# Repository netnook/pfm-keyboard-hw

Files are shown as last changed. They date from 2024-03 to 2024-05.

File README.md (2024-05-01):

# PFM keyboard

This repo contains the hardware design for the PFM (Perfect For Me) keyboard.
This is a 38 key split keyboard which - as hinted by the name - is designed specifically for me, 
my hands, my typing habits and so on. 

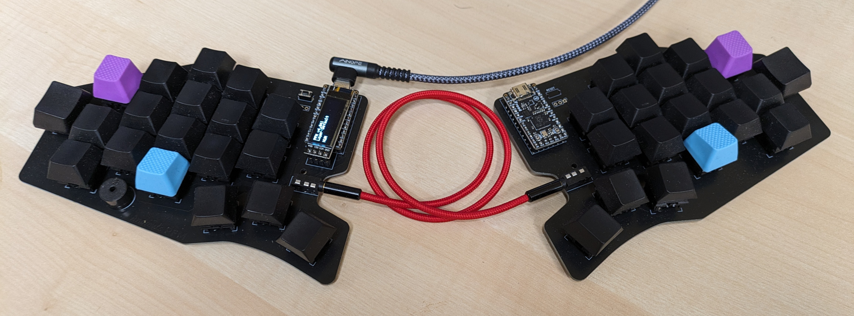
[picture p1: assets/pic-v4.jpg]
My keyboard


**Outline**

Shape Outline

In particular: 
- it has a relatively strong stagger
- the inner most index finger colum has only two keys
- the top most keys of the pinky column are actually used with the ring fingers (those keys are 
spaced a little further up)
- the outer most columns have only one key for the pinky to find.  

Together this reduces overstretching leading to better comfort and reduces the need for hand movement and my tendency to loose my home position when I do so.
Despite the name, it is still not perfect.

*Note: I actually don't use the fourth (lowest) key in the middle finger column - my middle finger does not seem to be able to memorize 2 different downward 
travel distances - and it will likely be removed in a future version.*

The keyboard is based on the [frood microcontroller](https://42keebs.eu/shop/parts/controllers/frood-rp2040-pro-micro-controller/) which allows the use of 38 keys without any diodes.

The board uses MX keys both with hot-swap sockets or directly soldered.

QMK based firmware for this board is available in the [pfm-keyboard-fw](https://github.com/netnook/pfm-keyboard-fw) repo.

## Schematic

Schematic

[Schematic as PDF](/assets/schematic.pdf)

## Parts

- 2x [frood microcontroller](https://42keebs.eu/shop/parts/controllers/frood-rp2040-pro-micro-controller/)
- sockets for MCU (optional)
- OLED display (link ?)
- sockets for display (this also allows bridging the distance required to allow the display to lay above the mcu - long pins could be used instead)
- 38x MX switches and keycaps of choice 
- 38x MX sockets - (optional - PCB can be used with or without sockets)
- 1 or 2 reset switches such as [this](https://42keebs.eu/shop/parts/components/reset-switch/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) - (optional - right hand side only needs programming once and the tiny reset switch on the mcu does the job, for the left hand side which is re-programmed with every layout change the switch is convenient to have)
- piezo buzzer (source ?)
- 2x TRRS socket such as [this](https://42keebs.eu/shop/parts/components/pj-320-trrs-socket/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)
- 1x TRRS or TRS cable
- USB cable for connection to PC
- rubber feet (8mm diameter, at least 2mm thick - preferably 3mm thick)

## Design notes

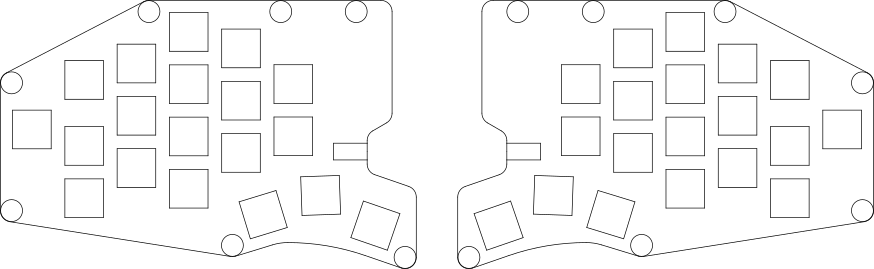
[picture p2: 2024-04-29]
assets/shape.png

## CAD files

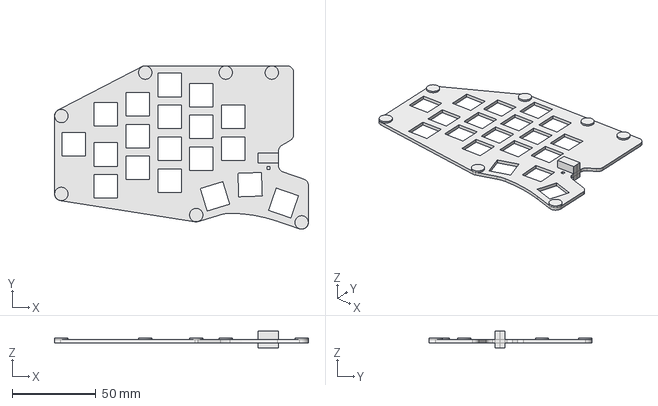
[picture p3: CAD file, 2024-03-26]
cad/diy-keyboard.FCStd
152.0 x 97.8 x 10.0 mm

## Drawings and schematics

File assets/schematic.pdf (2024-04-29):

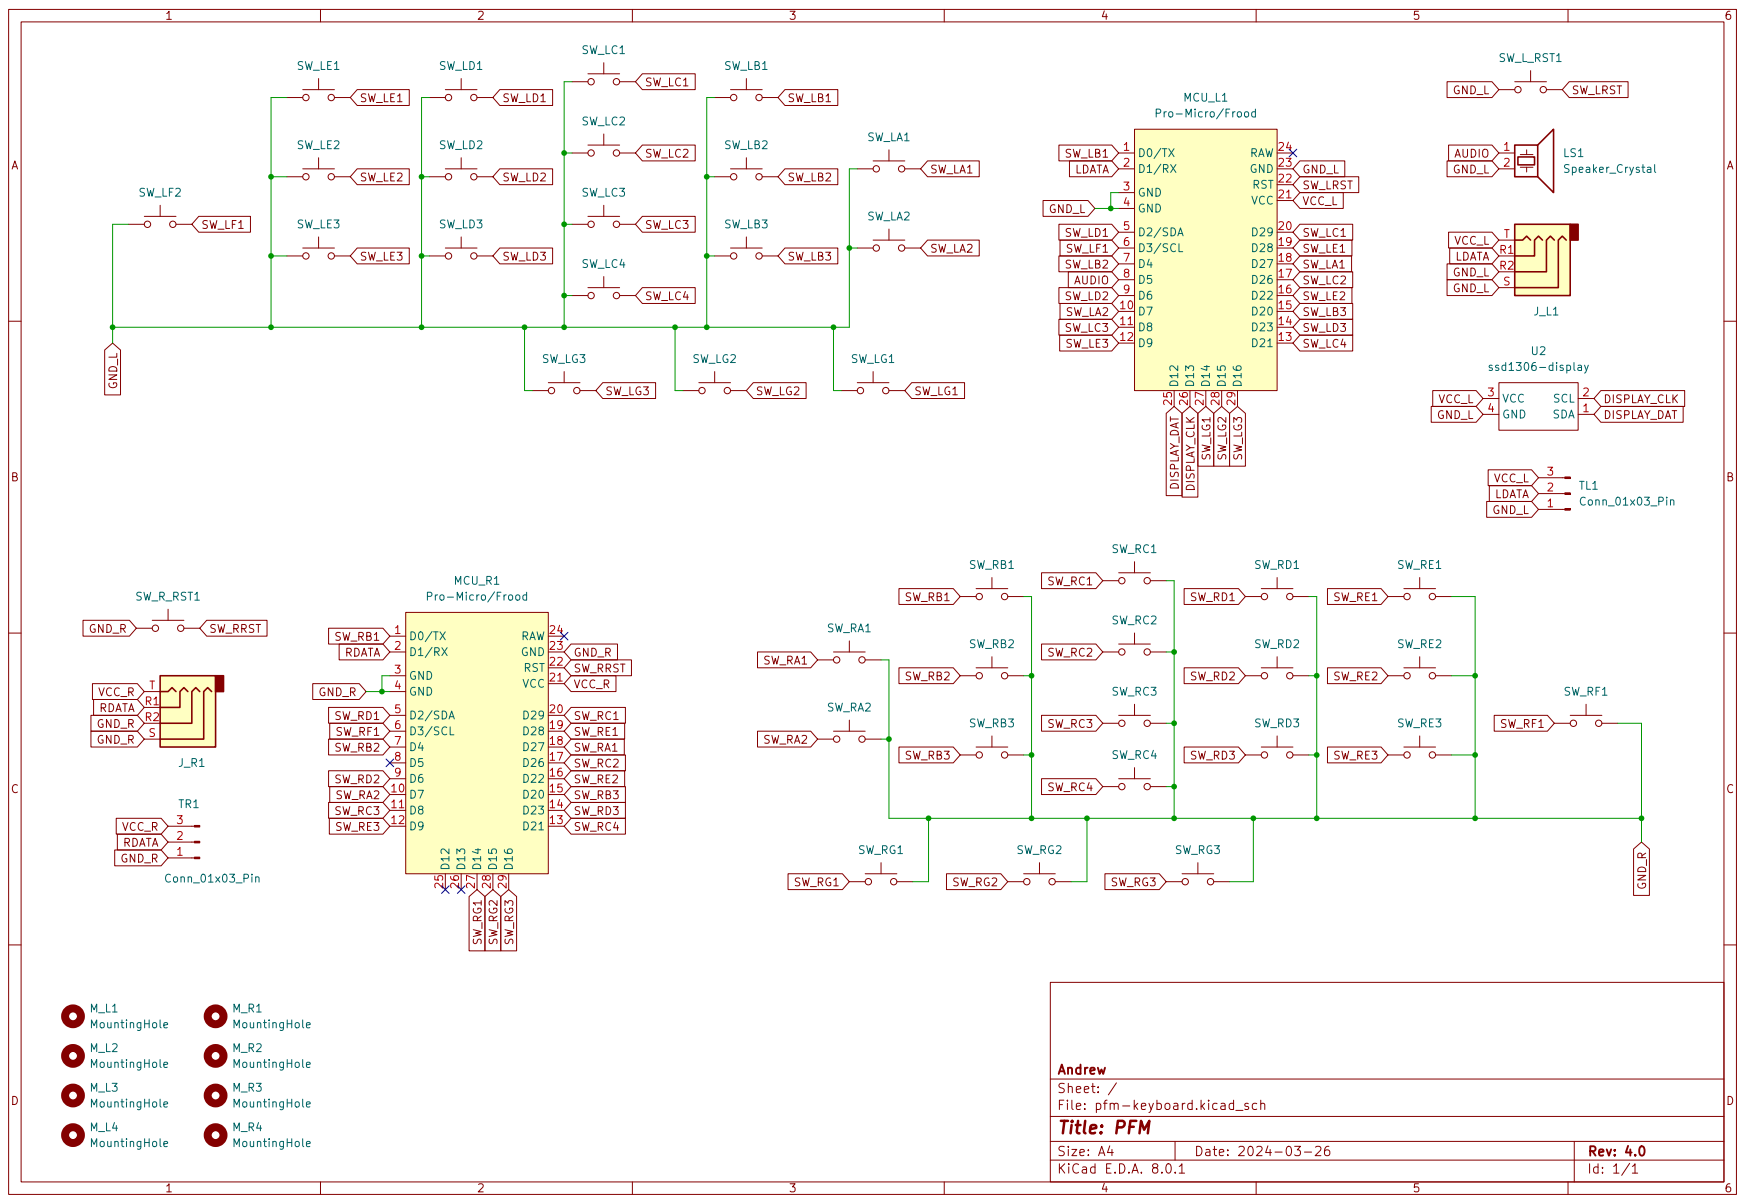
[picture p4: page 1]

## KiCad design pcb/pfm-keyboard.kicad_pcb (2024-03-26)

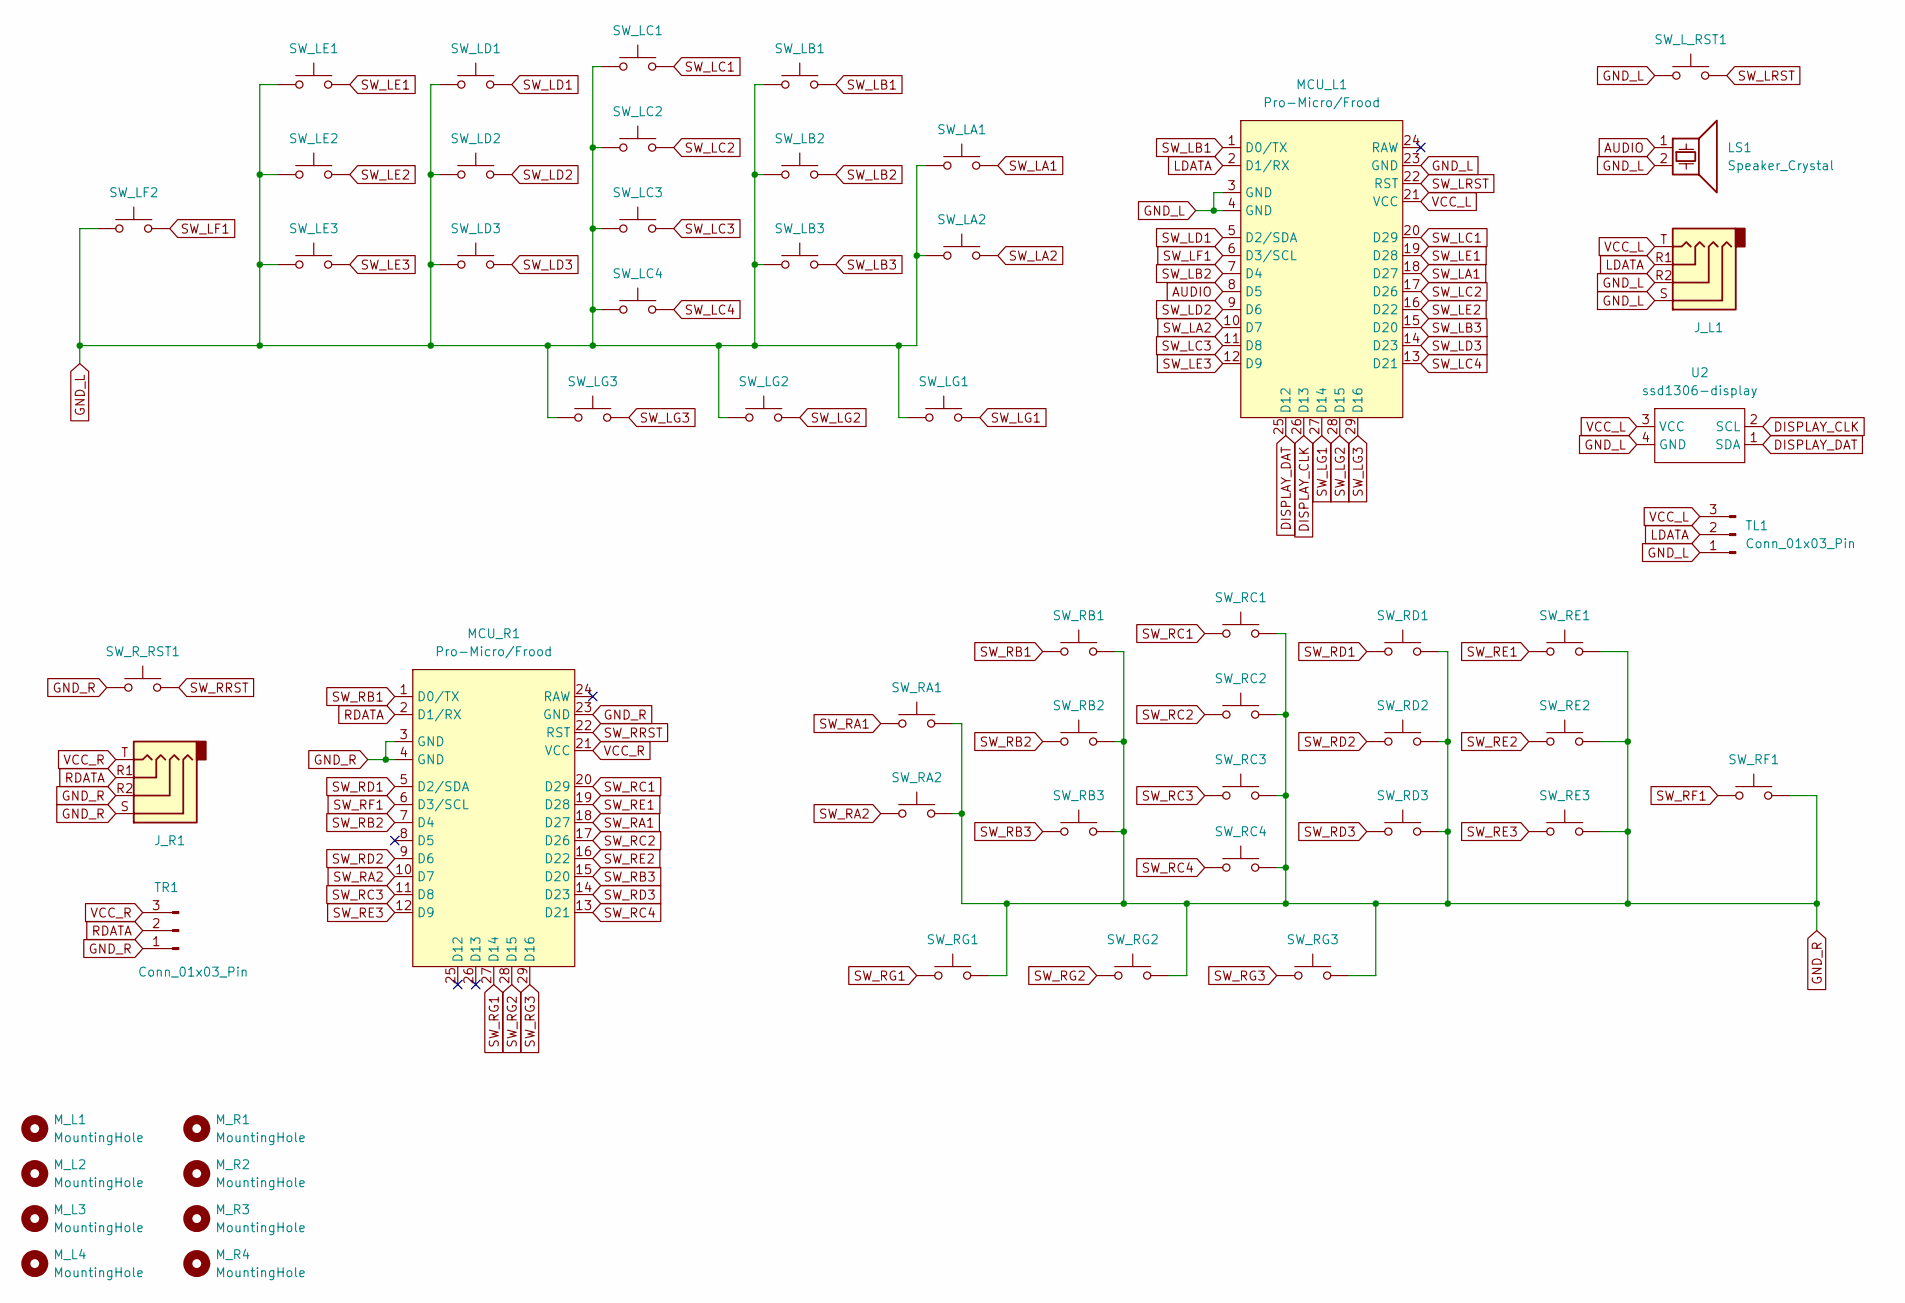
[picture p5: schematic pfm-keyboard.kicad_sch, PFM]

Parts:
J_L1: AudioJack4; trrs-socket
J_R1: AudioJack4; trrs-socket
LS1: Speaker_Crystal; buzzer-12x8.2-6.6
MCU_L1: Pro-Micro/Frood; frood
MCU_R1: Pro-Micro/Frood; frood
M_L1, M_L2, M_L3, M_L4: MountingHole; MountingHole_2.7mm_M2.5
M_R1, M_R2, M_R3, M_R4: MountingHole; MountingHole_2.7mm_M2.5
SW_LA1, SW_LA2: SW_Push; mx-socket-hs-and-solder
SW_LB1, SW_LB2, SW_LB3: SW_Push; mx-socket-hs-and-solder
SW_LC1, SW_LC2, SW_LC3, SW_LC4: SW_Push; mx-socket-hs-and-solder
SW_LD1, SW_LD2, SW_LD3: SW_Push; mx-socket-hs-and-solder
SW_LE1, SW_LE2, SW_LE3: SW_Push; mx-socket-hs-and-solder
SW_LF2: SW_Push; mx-socket-hs-and-solder
SW_LG1, SW_LG2, SW_LG3: SW_Push; mx-socket-hs-and-solder
SW_L_RST1: SW_Push; reset-switch
SW_RA1, SW_RA2: SW_Push; mx-socket-hs-and-solder
SW_RB1, SW_RB2, SW_RB3: SW_Push; mx-socket-hs-and-solder
SW_RC1, SW_RC2, SW_RC3, SW_RC4: SW_Push; mx-socket-hs-and-solder
SW_RD1, SW_RD2, SW_RD3: SW_Push; mx-socket-hs-and-solder
SW_RE1, SW_RE2, SW_RE3: SW_Push; mx-socket-hs-and-solder
SW_RF1: SW_Push; mx-socket-hs-and-solder
SW_RG1, SW_RG2, SW_RG3: SW_Push; mx-socket-hs-and-solder
SW_R_RST1: SW_Push; reset-switch
TL1: Conn_01x03_Pin; PinHeader_1x03_P2.54mm_Vertical
TR1: Conn_01x03_Pin; PinHeader_1x03_P2.54mm_Vertical
U2: ssd1306-display; display-128x32

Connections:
AUDIO: LS1.1, MCU_L1.8 (D5)
DISPLAY_CLK: MCU_L1.26 (D13), U2.2 (SCL)
DISPLAY_DAT: MCU_L1.25 (D12), U2.1 (SDA)
GND_L: J_L1.R2, J_L1.S, LS1.2, MCU_L1.3 (GND), MCU_L1.4 (GND), MCU_L1.23 (GND), SW_LA1.2, SW_LA2.2, SW_LB1.2, SW_LB2.2, SW_LB3.2, SW_LC1.2, SW_LC2.2, SW_LC3.2, SW_LC4.2, SW_LD1.2, SW_LD2.2, SW_LD3.2, SW_LE1.2, SW_LE2.2, SW_LE3.2, SW_LF2.2, SW_LG1.1, SW_LG2.1, SW_LG3.2, SW_L_RST1.1, TL1.1, U2.4 (GND)
GND_R: J_R1.R2, J_R1.S, MCU_R1.3 (GND), MCU_R1.4 (GND), MCU_R1.23 (GND), SW_RA1.1, SW_RA2.1, SW_RB1.1, SW_RB2.1, SW_RB3.1, SW_RC1.1, SW_RC2.1, SW_RC3.1, SW_RC4.1, SW_RD1.1, SW_RD2.1, SW_RD3.1, SW_RE1.1, SW_RE2.1, SW_RE3.1, SW_RF1.1, SW_RG1.2, SW_RG2.2, SW_RG3.1, SW_R_RST1.2, TR1.1
LDATA: J_L1.R1, MCU_L1.2 (D1/RX), TL1.2
RDATA: J_R1.R1, MCU_R1.2 (D1/RX), TR1.2
SW_LA1: MCU_L1.18 (D27), SW_LA1.1
SW_LA2: MCU_L1.10 (D7), SW_LA2.1
SW_LB1: MCU_L1.1 (D0/TX), SW_LB1.1
SW_LB2: MCU_L1.7 (D4), SW_LB2.1
SW_LB3: MCU_L1.15 (D20), SW_LB3.1
SW_LC1: MCU_L1.20 (D29), SW_LC1.1
SW_LC2: MCU_L1.17 (D26), SW_LC2.1
SW_LC3: MCU_L1.11 (D8), SW_LC3.1
SW_LC4: MCU_L1.13 (D21), SW_LC4.1
SW_LD1: MCU_L1.5 (D2/SDA), SW_LD1.1
SW_LD2: MCU_L1.9 (D6), SW_LD2.1
SW_LD3: MCU_L1.14 (D23), SW_LD3.1
SW_LE1: MCU_L1.19 (D28), SW_LE1.1
SW_LE2: MCU_L1.16 (D22), SW_LE2.1
SW_LE3: MCU_L1.12 (D9), SW_LE3.1
SW_LF1: MCU_L1.6 (D3/SCL), SW_LF2.1
SW_LG1: MCU_L1.27 (D14), SW_LG1.2
SW_LG2: MCU_L1.28 (D15), SW_LG2.2
SW_LG3: MCU_L1.29 (D16), SW_LG3.1
SW_LRST: MCU_L1.22 (RST), SW_L_RST1.2
SW_RA1: MCU_R1.18 (D27), SW_RA1.2
SW_RA2: MCU_R1.10 (D7), SW_RA2.2
SW_RB1: MCU_R1.1 (D0/TX), SW_RB1.2
SW_RB2: MCU_R1.7 (D4), SW_RB2.2
SW_RB3: MCU_R1.15 (D20), SW_RB3.2
SW_RC1: MCU_R1.20 (D29), SW_RC1.2
SW_RC2: MCU_R1.17 (D26), SW_RC2.2
SW_RC3: MCU_R1.11 (D8), SW_RC3.2
SW_RC4: MCU_R1.13 (D21), SW_RC4.2
SW_RD1: MCU_R1.5 (D2/SDA), SW_RD1.2
SW_RD2: MCU_R1.9 (D6), SW_RD2.2
SW_RD3: MCU_R1.14 (D23), SW_RD3.2
SW_RE1: MCU_R1.19 (D28), SW_RE1.2
SW_RE2: MCU_R1.16 (D22), SW_RE2.2
SW_RE3: MCU_R1.12 (D9), SW_RE3.2
SW_RF1: MCU_R1.6 (D3/SCL), SW_RF1.2
SW_RG1: MCU_R1.27 (D14), SW_RG1.1
SW_RG2: MCU_R1.28 (D15), SW_RG2.1
SW_RG3: MCU_R1.29 (D16), SW_RG3.2
SW_RRST: MCU_R1.22 (RST), SW_R_RST1.1
VCC_L: J_L1.T, MCU_L1.21 (VCC), TL1.3, U2.3 (VCC)
VCC_R: J_R1.T, MCU_R1.21 (VCC), TR1.3

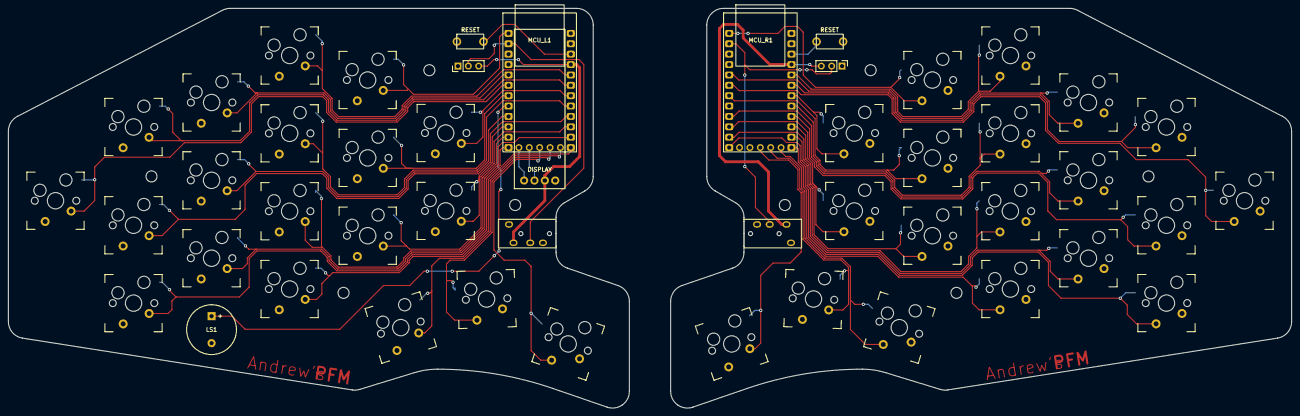
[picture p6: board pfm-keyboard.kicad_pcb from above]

Board: 2 copper layers, 314.1 x 97.8 mm, 56 parts (0 on the bottom side), 49 nets.

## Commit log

2024-03-03 import cad files
    [diy-keyboard.FCStd]
2024-03-03 import kicad files
    [pfm-keyboard.kicad_pcb, pfm-keyboard.kicad_sch]
2024-03-03 switched connections on TRRS jack for compatibility with TRS cables
    [pfm-keyboard.kicad_pcb, pfm-keyboard.kicad_sch]
2024-03-06 Use same MCU pins on left and right to avoid problems when right is master. Added mounting holes to schematic.
    [pfm-keyboard.kicad_pcb, pfm-keyboard.kicad_sch]
2024-03-17 Add TRS connector model and position on board
    [diy-keyboard.FCStd]
2024-03-26 Version 4 - better key placement, same pin usage on left and right, added test points
    [diy-keyboard.FCStd, pfm-keyboard.kicad_pcb, pfm-keyboard.kicad_sch]
2024-05-01 Note about removing lowest middle finger key in future.
